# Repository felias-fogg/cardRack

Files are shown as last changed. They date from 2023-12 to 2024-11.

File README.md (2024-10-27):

# An IoT Card Rack: cardRack

This is a project description showing how to build a 3D-printed card rack that signals how many slots are used over LTE-M. 

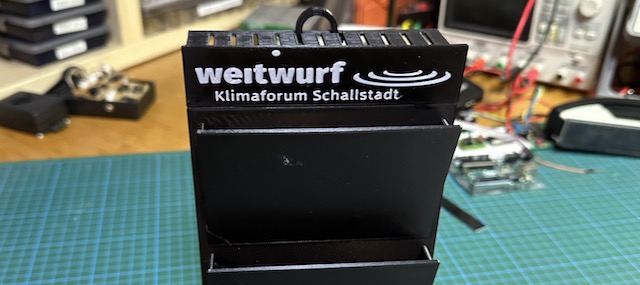
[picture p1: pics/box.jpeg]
Box


### Hardware

The IoT rack uses the IR sensors APDS-9930 for presence sensing and the AVR-IoT Cell Mini board EV70N78A by Microchip as the controller and LTE-M board. Since the sensors use all the same I2C address, they have to be on separate I2C buses. However, all in all, the hardware is very minimal, as one can see in the Fritzing sketch below. The Feather board is actually the mentioned EV70N78A board and not the Feather 328P. Since they have identical pin assignments and there is no Fritzing part for the former one,  I used the latter one.

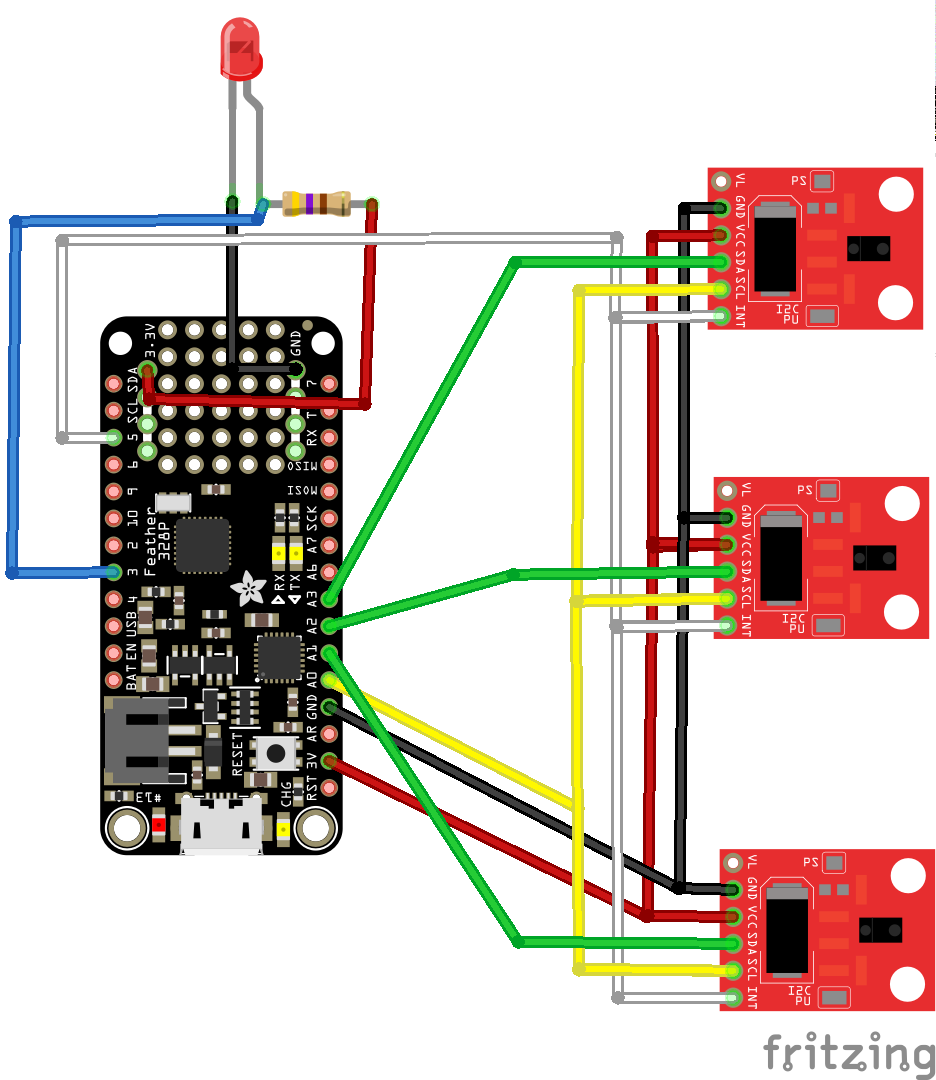
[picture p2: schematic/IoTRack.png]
Fritzing sketch


While the initial version was built on a Featherwing doubler, which looks quite ugly, I have now created a PCB. The KiCAD design data can be found in the [pcb](pcb) directory. 

### Software

The software is quite simple. An interrupt is triggered if a card is removed or inserted. Then, the sensors are polled to check the number of used slots. Finally, a short message is sent via an HTTPS POST command to a webserver, where a CGI script stores the number of occupied slots. One can use the stored number in a Javascript script to display it on a web page. 

To monitor that everything is working, the AVR chip is woken up every 2 hours, and a message with the number of occupied slots is sent. If the last message received is over 3 hours old, the information will no longer be considered valid.

### 3D Print Data

The 3D print data for the physical card rack can be found on [printables.com](https://www.printables.com/model/1051824-iot-card-rack-badge-holder).

### Folders

The repository contains the following folders:
* [IoTRack](IoTRack): The Arduino sketch
* [pics](pics): Some photos
* [schematic](schematic): A Fritzing schematic of the electronics
* [web](web): CGI script, an example bash script to trigger the CGI script, and an example web page 
* [pcb](pcb): KiCAD design files

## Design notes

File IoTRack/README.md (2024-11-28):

# IoTRack: The Firmware for cardRack

This is an Arduino sketch that implements the IoT Card Rack. It has been designed to run on an AVR-IoT Cellular Mini board, which contains among other things an AVR128DB48 MCU and a LTE-M cellular modem.   You need to install the DxCore in order to compile the software. Before you do so, you may want to get familiar with the board and how it communicates with the environment and the Internet. I recommend to read my [blog post](https://arduino-craft-corner.de/index.php/2024/01/03/connecting-the-avr-iot-cellular-mini-board-to-the-internet/) for this purpose. 

Before you upload the software to your board, you should make sure that you have defined the right location, have run the `genlocation.sh` script in the `web/config` folder, and have set a few other compile time constants in the sketch. Make also sure that in the Arduino IDE the right board with the right parameters are selected (see top of Arduino sketch). By setting the compile time constant `CALIB_SENSORS` to 1, you will get a steady stream of sensor measurements on the serial line, which may be helpful when setting the two thresholds `PROX_INT_LOW` and `PROX_INT_HIGH`.

A last addition was the compile-time constant `LEDSINK`. It should be set in the location header file and describes whether the wiring is similar to the one in the Fritzing sketch (when set to 1) or similar to the wiring as given in the KiCAD schema and PCB V1.0 (=0).

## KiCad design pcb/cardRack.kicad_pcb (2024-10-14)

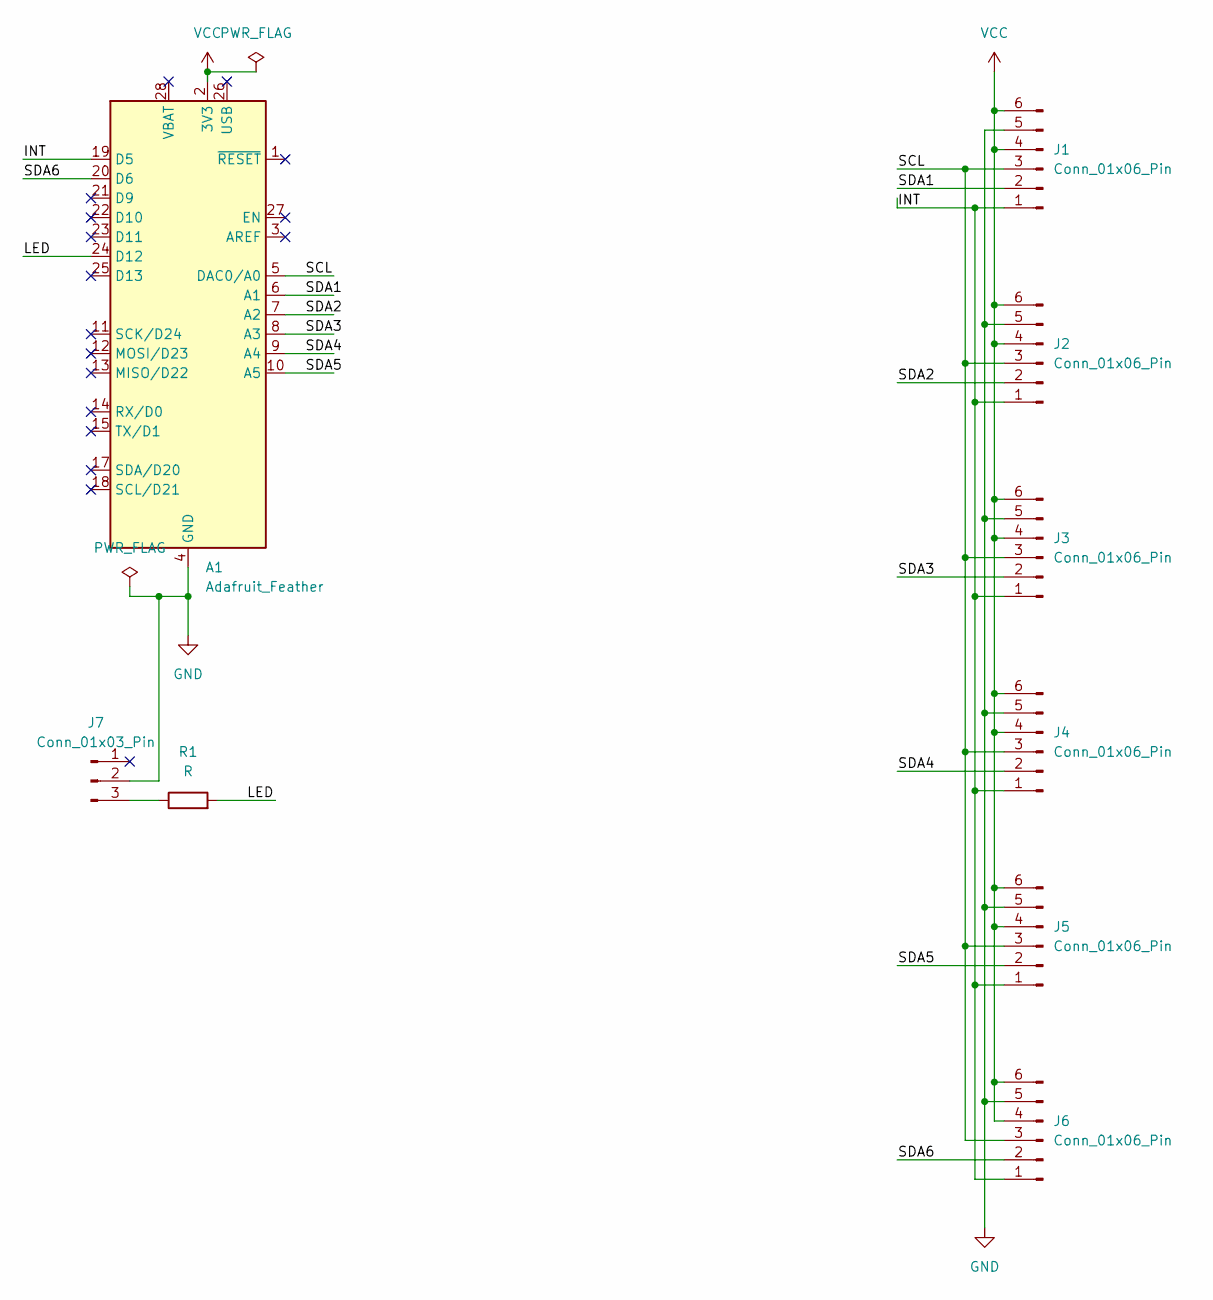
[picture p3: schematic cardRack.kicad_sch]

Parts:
A1: Adafruit_Feather
J1, J2, J3, J4, J5, J6: Conn_01x06_Pin; PinHeader_1x06_P2.54mm_Vertical
J7: Conn_01x03_Pin; PinHeader_1x03_P2.54mm_Vertical
R1: R; R_1206_3216Metric_Pad1.30x1.75mm_HandSolder

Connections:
/INT: A1.19 (D5), J1.1, J2.1, J3.1, J4.1, J5.1, J6.1
/LED: A1.24 (D12), R1.2
/SCL: A1.5 (DAC0/A0), J1.3, J2.3, J3.3, J4.3, J5.3, J6.3
/SDA1: A1.6 (A1), J1.2
/SDA2: A1.7 (A2), J2.2
/SDA3: A1.8 (A3), J3.2
/SDA4: A1.9 (A4), J4.2
/SDA5: A1.10 (A5), J5.2
/SDA6: A1.20 (D6), J6.2
GND: A1.4 (GND), A1.16 (GND), J1.5, J2.5, J3.5, J4.5, J5.5, J6.5, J7.2
unnamed: J7.3, R1.1
VCC: A1.2 (3V3), J1.4, J1.6, J2.4, J2.6, J3.4, J3.6, J4.4, J4.6, J5.4, J5.6, J6.4, J6.6

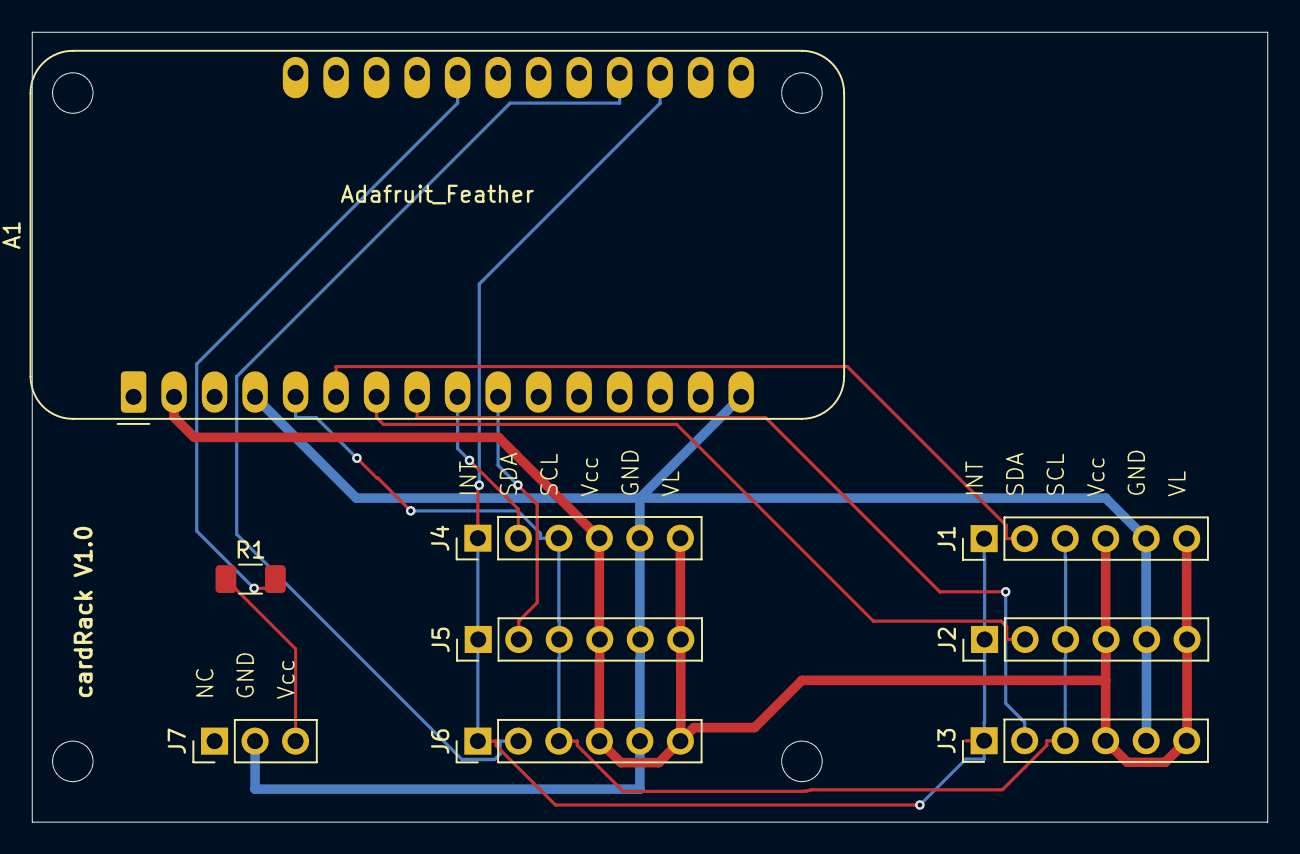
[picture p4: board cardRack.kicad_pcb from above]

Board: 2 copper layers, 77.5 x 49.5 mm, 9 parts (0 on the bottom side), 12 nets.

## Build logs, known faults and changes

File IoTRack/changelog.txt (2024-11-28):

Changelog for IoTRack
---------------------

V0.2.0
- First version using the sensors

V0.2.1
- CHANGED: Using persistence for the proximity interrupts
  5 consecutive measurements with a cycle time of 700 ms 

V0.3.0
- FIX: switched from ISR to attachInterrupt; this became necessary because
  with "attachInterrupt: Only enabled ports" (which you need when using ISRs)
  all the example scripts for the board crashed. So, you defintely need to set
  attachInterrupt: On all pins, with new implementation"!
  
V0.3.1
- ADDED: count number of tickets present
- ADDED: integrate LTE-M sending
- ADDED: error handling: blink fast
- ADDED: blink slowly when awake

V0.3.2
- CHANGE: change status LED from D13 to D12 and toggle between input and output (LOW)
- FIX: added a check for being in power down mode (in_power_down()) in order to avoid switching
  off the LED after it has been assigned the sleep state value

V0.9.0
- CHANGE: LOC is now the constant that signifies which version of the firmware
  should be generated. In order to have a system that compiles, "example" is
  the default location (with associated server and password in
  web/config/example.conf) and a generated example.h include file.
- CHANGE: The example web page contains now php code
- ADDED: In addition, there is a Wordpress code snippet that can be used to display
  the number of available cards 

V0.9.1
- FIX: switch off LTE when there was an error and we stop.
- FIX: reset globalerror in connectToNetwork only if the error
  was an connection error

V0.9.2
- FIX: Addressed the potential race condition that could result from a hectic user
  who takes out a card (values are changed) and then puts it back. This might
  result in an early interrupt that might go undected and then later events will
  not be registered because the interrupt is edge based.
- FIX: In addition, all interrupt flags are cleared again when verifying the
  initial values. This makes sure that it is impossible to enter sleep state
  with a IRQ line that is low because of an proximity interrupt.

V0.9.3
- ADDED: Print date/time when entering the loop
- CHANGE: Change sleep time to one hour
- CHANGE: Raise sensor error when sensor value is 0
- CHANGE: Changed example.php so that it conforms with the wordpress code snippet
- ADDED: The code snippet is now also a file in the server folder

V0.9.4
- CHANGED: Changed threshold values to 250/300 so that even black paper is reliably recognized
- There is now a pcb directory in the repo, which contains pcb design data

V1.0.0
- ADDED: compile time constant LEDSINK, which needs to be set in the
  location header file; should be 1 for the wiring as shown in the
  Fritzing and 0 if the CardRack PCB is used.

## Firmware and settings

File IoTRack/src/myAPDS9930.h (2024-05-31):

/**
 * @file    myAPDS-9930.h
 * @brief   Library for the SparkFun APDS-9930 breakout board
 * @author  Shawn Hymel (SparkFun Electronics)
 *
 * @copyright	This code is public domain but you buy me a beer if you use
 * this and we meet someday (Beerware license).
 *
 * This library interfaces the Avago APDS-9930 to Arduino over I2C. The library
 * relies on the Arduino Wire (I2C) library. to use the library, instantiate an
 * APDS9930 object, call init(), and call the appropriate functions.
 * I modified the library so it can rely on the FlexWireLocal library (Bernhard Nebel)
 */
 
#ifndef myAPDS9930_H
#define myAPDS9930_H

#include <Arduino.h>
#include <log.h>

/* Debug */
//#define DEBUG                   0

/* APDS-9930 I2C address */
#define APDS9930_I2C_ADDR       0x39

/* Command register modes */
#define REPEATED_BYTE           0x80
#define AUTO_INCREMENT          0xA0
#define SPECIAL_FN              0xE0

/* Error code for returned values */
#define ERROR                   0xFF

/* Acceptable device IDs */
#define APDS9930_ID_1           0x12
#define APDS9930_ID_2           0x39

/* Misc parameters */
#define FIFO_PAUSE_TIME         30      // Wait period (ms) between FIFO reads

/* APDS-9930 register addresses */
#define APDS9930_ENABLE         0x00
#define APDS9930_ATIME          0x01
#define APDS9930_WTIME          0x03
#define APDS9930_AILTL          0x04
#define APDS9930_AILTH          0x05
#define APDS9930_AIHTL          0x06
#define APDS9930_AIHTH          0x07
#define APDS9930_PILTL          0x08
#define APDS9930_PILTH          0x09
#define APDS9930_PIHTL          0x0A
#define APDS9930_PIHTH          0x0B
#define APDS9930_PERS           0x0C
#define APDS9930_CONFIG         0x0D
#define APDS9930_PPULSE         0x0E
#define APDS9930_CONTROL        0x0F
#define APDS9930_ID             0x12
#define APDS9930_STATUS         0x13
#define APDS9930_Ch0DATAL       0x14
#define APDS9930_Ch0DATAH       0x15
#define APDS9930_Ch1DATAL       0x16
#define APDS9930_Ch1DATAH       0x17
#define APDS9930_PDATAL         0x18
#define APDS9930_PDATAH         0x19
#define APDS9930_POFFSET        0x1E


/* Bit fields */
#define APDS9930_PON            0b00000001
#define APDS9930_AEN            0b00000010
#define APDS9930_PEN            0b00000100
#define APDS9930_WEN            0b00001000
#define APSD9930_AIEN           0b00010000
#define APDS9930_PIEN           0b00100000
#define APDS9930_SAI            0b01000000

/* On/Off definitions */
#define OFF                     0
#define ON                      1

/* Acceptable parameters for setMode */
#define POWER                   0
#define AMBIENT_LIGHT           1
#define PROXIMITY               2
#define WAIT                    3
#define AMBIENT_LIGHT_INT       4
#define PROXIMITY_INT           5
#define SLEEP_AFTER_INT         6
#define ALL                     7

/* LED Drive values */
#define LED_DRIVE_100MA         0
#define LED_DRIVE_50MA          1
#define LED_DRIVE_25MA          2
#define LED_DRIVE_12_5MA        3

/* Proximity Gain (PGAIN) values */
#define PGAIN_1X                0
#define PGAIN_2X                1
#define PGAIN_4X                2
#define PGAIN_8X                3

/* ALS Gain (AGAIN) values */
#define AGAIN_1X                0
#define AGAIN_8X                1
#define AGAIN_16X               2
#define AGAIN_120X              3

/* Interrupt clear values */
#define CLEAR_PROX_INT          0xE5
#define CLEAR_ALS_INT           0xE6
#define CLEAR_ALL_INTS          0xE7

/* Default values */
#define DEFAULT_ATIME           0xFF
#define DEFAULT_WTIME           0xFF
#define DEFAULT_PTIME           0xFF
#define DEFAULT_PPULSE          0x08
#define DEFAULT_POFFSET         0       // 0 offset
#define DEFAULT_CONFIG          0
#define DEFAULT_PDRIVE          LED_DRIVE_100MA
#define DEFAULT_PDIODE          2
#define DEFAULT_PGAIN           PGAIN_8X
#define DEFAULT_AGAIN           AGAIN_16X
#define DEFAULT_PILT            0       // Low proximity threshold
#define DEFAULT_PIHT            50      // High proximity threshold
#define DEFAULT_AILT            0xFFFF  // Force interrupt for calibration
#define DEFAULT_AIHT            0
#define DEFAULT_PERS            0x22    // 2 consecutive prox or ALS for int.

/* ALS coefficients */
#define DF                      52
#define GA                      0.49
#define B                       1.862
#define C                       0.746
#define D                       1.291

/* State definitions */
enum {
  NA_STATE,
  NEAR_STATE,
  FAR_STATE,
  ALL_STATE
};

/* APDS9930 Class */
class APDS9930 {
public:

    /* Initialization methods */
    APDS9930();
    ~APDS9930();
    bool init();
    uint8_t getMode();
    bool setMode(uint8_t mode, uint8_t enable);
    
    /* Turn the APDS-9930 on and off */
    bool enablePower();
    bool disablePower();
    
    /* Enable or disable specific sensors */
    bool enableLightSensor(bool interrupts = false);
    bool disableLightSensor();
    bool enableProximitySensor(bool interrupts = false);
    bool disableProximitySensor();

    /* LED drive strength control */
    uint8_t getLEDDrive();
    bool setLEDDrive(uint8_t drive);
    // uint8_t getGestureLEDDrive();
    // bool setGestureLEDDrive(uint8_t drive);
    
    /* Gain control */
    uint8_t getAmbientLightGain();
    bool setAmbientLightGain(uint8_t gain);
    uint8_t getProximityGain();
    bool setProximityGain(uint8_t gain);
    bool setProximityDiode(uint8_t drive);
    uint8_t getProximityDiode();

    
    /* Get and set light interrupt thresholds */
    bool getLightIntLowThreshold(uint16_t &threshold);
    bool setLightIntLowThreshold(uint16_t threshold);
    bool getLightIntHighThreshold(uint16_t &threshold);
    bool setLightIntHighThreshold(uint16_t threshold);
    
    /* Get and set interrupt enables */
    uint8_t getAmbientLightIntEnable();
    bool setAmbientLightIntEnable(uint8_t enable);
    uint8_t getProximityIntEnable();
    bool setProximityIntEnable(uint8_t enable);
    
    /* Clear interrupts */
    bool clearAmbientLightInt();
    bool clearProximityInt();
    bool clearAllInts();
    
    /* Proximity methods */
    bool readProximity(uint16_t &val);

    /* Ambient light methods */
    bool readAmbientLightLux(float &val);
    bool readAmbientLightLux(unsigned long &val);
    float floatAmbientToLux(uint16_t Ch0, uint16_t Ch1);
    unsigned long ulongAmbientToLux(uint16_t Ch0, uint16_t Ch1);
    bool readCh0Light(uint16_t &val);
    bool readCh1Light(uint16_t &val);
    
//private:

    /* Proximity Interrupt Threshold */
    uint8_t getProximityIntLowThreshold();
    bool setProximityIntLowThreshold(uint16_t threshold);
    uint8_t getProximityIntHighThreshold();
    bool setProximityIntHighThreshold(uint16_t threshold);
    
    /* Raw I2C Commands */
    bool wireWriteByte(uint8_t val);
    bool wireWriteDataByte(uint8_t reg, uint8_t val);
    bool wireWriteDataBlock(uint8_t reg, uint8_t *val, unsigned int len);
    bool wireReadDataByte(uint8_t reg, uint8_t &val);
    int wireReadDataBlock(uint8_t reg, uint8_t *val, unsigned int len);
};

extern FlexWire flex;

#endif

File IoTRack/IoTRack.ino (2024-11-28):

// This is an Arduino sketch to implement an  IoT card rack
// using the AVR-IoT Cellular Mini board.

// Configure the Arduino IDE as follows:
// "AVR-DB series (no bootloader)" under DxCore
// Chip: AVR128DB48
// Wire Library mode: 2x Wire, Master or Slave
// Programmer: Curiosity Nano
// printf: Full, 2.6k, print floats

// Pin mapping:
// A0 = PIN_PD6
// A1 = PIN_PD1
// A2 = PIN_PD3
// A3 = PIN_PD4
// A4 = PIN_PD5
// A5 = PIN_PD7
// D5 = PIN_PE2
// D6 = PIN_PE1
// D9 = PIN_PD0
// D10 = PIN_PB5
// D11 = PIN_PD2 (SW0, DBG2)
// D12 = PIN_PA7
// D13 = PIN_PB2 (LED4, DBG1)

#define VERSION "1.0.0" 

#define CALIB_SENSORS 0

// define the right LOCATION!
#define EXAMPLE_LOC 0
#define SCHALLSTADT_LOC 1
#define MENGEN_LOC 2

#define LOC MENGEN_LOC
#if LOC == EXAMPLE_LOC
#include "example.h"
#elif LOC == SCHALLSTADT_LOC
#include "schallstadt.h"
#elif LOC == MENGEN_LOC
#include "mengen.h"
#endif

#define MAXSENSOR 3
#define PROX_INT_LOW 250
#define PROX_INT_HIGH 300
#define SLEEPTIME 60*60 // sleep time in seconds

#if CALIB_SENSORS
#define WEN 0    // no wait between two proximity tests
#define PPERS 0  // no persistence for proximity readings
#else
#define WEN 1
#define PPERS 5
#endif

#include <Arduino.h>
#include <mcp9808.h>
#include <veml3328.h>
#include <http_client.h>
#include <led_ctrl.h>
#include <log.h>
#include <lte.h>
#include <low_power.h>
#include <sequans_controller.h>
#include "src/FlexWire.h"
#include "src/myAPDS9930.h"

FlexWire flex;
APDS9930 sensor;

volatile bool isrflag = false;
volatile bool ledoff = true;
volatile int cnt = 0;
uint16_t proximity_data = 0;
uint8_t tickets;
enum class Error { NONE, CONNECTION, SENSOR };
volatile Error globalerror = Error::NONE;
bool highvalue[MAXSENSOR]; // measured high sensor values


const uint8_t sdapin[] = { PIN_PD1, PIN_PD3, PIN_PD4, PIN_PD5, PIN_PD7, PIN_PE1 }; //A1 .. D6
const uint8_t sclpin = PIN_PD6; //A0
const uint8_t irqpin = PIN_PE2; //D5 (note: this is a fully asynchronous pin!)
const uint8_t ledpin = PIN_PA7; //D12
const uint8_t lowqpin = PIN_PB4; // controls the LDO regulator (signalling power down)

void setup() {
  LedCtrl.begin();
  LedCtrl.startupCycle();

  Log.begin(115200);
  Log.setLogLevel(LogLevel::DEBUG);
  Log.info("");
  Log.infof(F("IoTRack Version %s\n\r"), VERSION);

  // Make sure sensors are turned off
  Veml3328.begin();
  Mcp9808.begin();
  Veml3328.shutdown();
  Mcp9808.shutdown();

  // init sensors
  initializeSensors();
  
  
#if !CALIB_SENSORS
  // Now we configure the low power module for power down configuration, where
  // the cellular modem and the CPU will be powered down
  LowPower.configurePowerDown();

  // init HTTP client
  initializeHTTP();

  // setup interrupt handling
  pinMode(irqpin, INPUT_PULLUP);
  attachInterrupt(digitalPinToInterrupt(irqpin), sensorISR_callback, FALLING);
#endif

  // setup extra timer for blinking
  TCB3.CCMP = 30000;
  TCB3.CTRLB = 0;
  TCB3.CTRLA = 5;
  TCB3.INTCTRL = 1;

  // Connect to network
  connectToNetwork();
  
  Log.info(F("Setup completed"));
#if !LEDSINK
  pinMode(ledpin, OUTPUT);
#endif
}

void loop() {
  logTime();
  tickets = readSensors();
  Log.infof(F("#tickets: %d\n\r"),tickets);
#if CALIB_SENSORS
  delay(1000);
#else
  sendData(tickets);
  if (globalerror != Error::NONE) {
    Lte.end();
    while (1);
  }
  delay(2000);
  if (!sameSensorReading()) {
    Log.debug(F("Sensor reading has changed"));
    return; // something has changed, evaluate again!
  }
  LowPower.powerDown(SLEEPTIME);
#endif
}

void logTime(void) {
  char response_buffer[64] = "";
  char * strix;
  // Get the time from the modem
  if (SequansController.writeCommand(F("AT+CCLK?"),
                                       response_buffer,
                                       sizeof(response_buffer)) !=
        ResponseResult::OK) {
    Log.error(F("Command for retrieving modem time failed"));
    Lte.end();
    globalerror = Error::CONNECTION;
    return;
  }
  strix = strchr(response_buffer, '"');
  if (strix == NULL) strix = response_buffer;
  Log.infof(F("Start of main loop: %s"), strix);
}

// periodic interrupt to signal data transfer and error conditions
ISR(TCB3_INT_vect) {
  if (in_power_down()) {
#if LEDSINK
    pinMode(ledpin, INPUT);
#else
    digitalWrite(ledpin, HIGH);
#endif
    TCB3.INTFLAGS = 1;
    return;
  }
  if (cnt-- <= 0) {
    ledoff = !ledoff;
    if (globalerror == Error::NONE) cnt = 6;
    else cnt = 1;
  }
#if LEDSINK
  if (ledoff) pinMode(ledpin, OUTPUT);
  else pinMode(ledpin, INPUT);
#else
  if (ledoff) digitalWrite(ledpin, LOW);
  else digitalWrite(ledpin, HIGH);
#endif
  TCB3.INTFLAGS = 1;
}

// checks whether we are in the power-down state
bool in_power_down(void) {
  return ((SLPCTRL.CTRLA & SLPCTRL_SEN_bm) != 0);
}
    
// This is the IRS for the IRQ line of the sensors
void sensorISR_callback(void) {
  isrflag = 1;
}

void initializeSensors(void) {
  for (uint8_t i=0; i < MAXSENSOR; i++) {
    Log.debugf(F("Sensor %d initialization\n\r"),i);
    flex.setPins(sdapin[i], sclpin);
    if (!sensor.init()) {
      Log.errorf(F("Error while initializing sensor %d\n\r"),i);
      globalerror = Error::SENSOR;
    }
    // Start running the APDS-9930 proximity sensor 
    if ( !sensor.enableProximitySensor(!CALIB_SENSORS) ) {
      Log.errorf(F("Something went wrong while enabling sensor %d\n\r"),i);
      globalerror = Error::SENSOR;
    }
    
    // Set proximity interrupt thresholds
    if ( !sensor.setProximityIntLowThreshold(PROX_INT_LOW) ) {
      Log.error(F("Error writing low threshold"));
      globalerror = Error::SENSOR;
    }
    if ( !sensor.setProximityIntHighThreshold(PROX_INT_HIGH) ) {
      Log.error(F("Error writing high threshold"));
    }
    
    // Enable wait timer
    if ( !sensor.setMode(WAIT, WEN) ) {
      Log.error(F("Something went wrong trying to set WEN=1"));
      globalerror = Error::SENSOR;
    }

    // Set wait time to long (700 ms)
    if( !sensor.wireWriteDataByte(APDS9930_WTIME, 0x00) ) {
      Log.error(F("Something went wrong trying to set WTIME=0"));
      globalerror = Error::SENSOR;
    }

    // set time scale to short
    if( !sensor.wireWriteDataByte(APDS9930_CONFIG, 0) ) {
      Log.error(F("Something went wrong trying to set WLONG=0"));
      globalerror = Error::SENSOR;
    }

    // Adjust the Proximity sensor gain
    if ( !sensor.setProximityGain(PGAIN_2X) ) {
      Log.error(F("Something went wrong trying to set PGAIN"));
      globalerror = Error::SENSOR;
    }

    // Setting persistence
    if ( !sensor.wireWriteDataByte(APDS9930_PERS, (PPERS<<4)) ) { // IRQ only after 5 meas.
      Log.error(F("Something went wrong trying to set persistence"));
      globalerror = Error::SENSOR;
    }
    
    // Adjust the Proximity LED drive
    if ( !sensor.setLEDDrive(LED_DRIVE_12_5MA) ) {
      Log.error(F("Something went wrong trying to set LED Drive"));
      globalerror = Error::SENSOR;
    }

    // Clear interrupt flag
    if ( !sensor.clearProximityInt() ) {
      Log.error(F("Error clearing interrupt"));
      globalerror = Error::SENSOR;
    }
  }
  Log.debug(F("All sensors initialized"));
}

int readSensors(void) {
  int high = 0;

  // Read the proximity value
  for (uint8_t i=0; i < MAXSENSOR; i++) {
    highvalue[i] = false;
    flex.setPins(sdapin[i], sclpin);
    if ( !sensor.readProximity(proximity_data) ) {
      Log.errorf(F("Error reading proximity value from sensor %d\n\r"),i);
      globalerror = Error::SENSOR;
    } 
    Log.debugf(F("Proximity (sensor %d): %d\n\r"), i, proximity_data);
    if (proximity_data == 0) {
      Log.errorf(F("Sensor value for ssensor %d is 0!\n\r"), i);
      globalerror = Error::SENSOR;
    }
    if (proximity_data < PROX_INT_LOW) {
      if (!sensor.setProximityIntLowThreshold(0)) {
	Log.errorf(F("Error setting low proximity threshold for sensor %d\n\r"),i);
	globalerror = Error::SENSOR;
      }
      if (!sensor.setProximityIntHighThreshold(PROX_INT_HIGH)) {
	Log.errorf(F("Error setting high proximity threshold for sensor %d\n\r"),i);
	globalerror = Error::SENSOR;
      }
    } else if (proximity_data > PROX_INT_HIGH) {
      high++;
      highvalue[i] = true;
      if (!sensor.setProximityIntLowThreshold(PROX_INT_LOW)) {
	Log.errorf(F("Error setting low proximity threshold for sensor %d\n\r"),i);
	globalerror = Error::SENSOR;
      }
      if (!sensor.setProximityIntHighThreshold(1023)) {
	Log.errorf(F("Error setting high proximity threshold for sensor %d\n\r"),i);
	globalerror = Error::SENSOR;
      }
    }	
    if ( !sensor.clearProximityInt() ) {
      Log.error(F("Error clearing interrupt"));
      globalerror = Error::SENSOR;
    }
  }
  return high;
}

// check if the sensor has still the same value as when
// measuring initially
bool sameSensorReading() {
  for (uint8_t i=0; i < MAXSENSOR; i++) {
    flex.setPins(sdapin[i], sclpin);
    sensor.clearProximityInt(); // clear interrupt again (just to be sure)
    sensor.readProximity(proximity_data);
    if  (proximity_data > PROX_INT_HIGH) {
      if (!highvalue[i]) return false;
    } else{
      if (highvalue[i]) return false;
    }
  }
  return true;
}

void initializeHTTP(void) {
  if (!HttpClient.configure(DOMAIN, 443, true)) {
    Log.error(F("Failed to configure https client\r\n"));
    globalerror = Error::CONNECTION;
    return;
  }
  Log.debug(F("Configured for HTTPS"));
}

/**
 * @brief Sends a payload with latitude, longitude and the timestamp.
 */
void sendData(int slots) {
  char data[80];

  sprintf_P(data, PSTR("LOCATION=%s&KEY=%s&TICKETS=%d"), LOCATION, PASSWORD, slots);

  connectToNetwork();

  Log.debugf(F("Data to send: %s\n\r"), data);
  HttpResponse response = HttpClient.post("/cgi-bin/storedata.cgi", data);
  Log.debugf(F("POST - HTTP status code: %u, data size: %u\r\n"),
	    response.status_code,
	    response.data_size);
  HttpClient.readBody(response.data_size + 16);
  Log.infof(F("Data transmitted: %d\n\r"), slots);
}

/**
 * @brief Connects to the network operator. Will block until connection is
 * achieved.
 */
void connectToNetwork() {
  int retry = 100; // connection tries before we go into error state
  // If we already are connected, don't do anything
  if (!Lte.isConnected()) {
    Log.info(F("Connect to network ..."));
    while (!Lte.begin() && retry--) {}
    if (!Lte.isConnected()) {
      globalerror = Error::CONNECTION;
      while (!Lte.begin()) { delay(30000); }
    }
    if (globalerror == Error::CONNECTION) globalerror = Error::NONE;
    Log.infof(F("Connected to operator: %s\r\n"),
	      Lte.getOperator().c_str());
  }
}

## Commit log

2023-12-27 Fritzing schematic added
    [IoTRack.fzz]
2024-10-27 Readme + Fritzing
    [IoTRack.fzz]
